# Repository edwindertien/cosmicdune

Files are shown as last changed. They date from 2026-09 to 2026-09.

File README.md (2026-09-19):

# cosmic dune -- sensor pod (manual)

One of 6 wearable pods for the *cosmic dune* project: an artistic laser
distress signal sent into the sky, triggered by 6 musicians' biosignals
synchronizing. Each pod reads one musician's heart rate (ear-clip pulse
sensor) and skin conductance (GSR), renders that live on a 250-LED strip
worn on the body and on an on-pod OLED display, and reports telemetry
over WiFi (OSC) to a central hub. The hub (gathering all 6 pods and
driving the Laserworld CUBE 3) is a separate, not-yet-built piece -- see
`context.md` for where that stands.

## Wiring

| Signal | Pico W pin  |
|---|---|
| Grove ear-clip signal | GP26 |
| Grove ear-clip VCC / GND | 3V3 / GND |
| GSR sensor signal | GP27 (ADC1) |
| GSR sensor VCC / GND | 3V3 / GND |
| LED strip data-in | GP17 |
| LED strip 5V / GND | **external 5V supply, NOT the Pico** -- common GND back to the Pico |
| OLED display (I2C0) SDA / SCL | GP8 / GP9 |
| M5Stack encoder (I2C1) SDA / SCL | GP6 / GP7 |

**Power, read this first:** 250x WS2812B at full white/full brightness is on
the order of 15A @ 5V -- far beyond USB or a small onboard regulator. Feed
the strip from its own adequately-rated 5V supply with a common ground back
to the Pico, and inject power at both ends of the 5m run if you see
dimming/colour-shift toward the far end. Normal operation (one travelling
comet, not the whole strip lit) draws much less than the full-white worst
case -- size the supply for the worst case anyway.

## Build

Requires [PlatformIO](https://platformio.org/) (VS Code extension or CLI).

```
pio run -t upload
pio device monitor
```

If the `pico_w` environment fails to resolve, check the note at the top of
`platformio.ini` -- the board id used by the `maxgerhardt` platform fork can
shift between versions. If a build fails on a missing header from a file
under `src/core/` or `src/net/`, double check that file actually exists at
that path locally -- these are newer folders in the project and it's easy
to end up with a file saved flat in `src/` instead of its subfolder.

## First bring-up (no sensors needed)

1. Flash and open the serial monitor (115200 baud).
2. `status` -- confirms the CLI is alive; should print `bpm=0 ... signal=no
   mode=ibi gsr=... net=off`.
3. `beat 72` -- injects one synthetic heartbeat. Confirms, with no sensors
   attached at all, that a white/blue comet travels the strip once, and
   the OLED's beat circle flashes with a pulse-waveform blip.
4. `beat 140 80` -- same, but with a synthetic 80% GSR level: the comet
   should read purple/red instead of white/blue (see `Config::gsrToColor`
   in `src/drivers/pulse_strip.cpp` to retune the gradient).
5. Clip on the ear-clip sensor, `stream on` -- watch live `bpm,ibiMs,signal`
   CSV lines. If `bpm` never moves off 0, or reads roughly double a manual
   pulse count, see the polarity note in `src/config.h` (`HW::PULSE_PIN`) --
   the sensor's beat edge may be RISING rather than the assumed FALLING on
   your specific module.
6. `gsr` -- watch the raw ADC count move as you rub your fingers together
   or relax. Set `gsr range <counts>` to whatever span actually takes you
   from white to red; `gsr invert on` if the colour runs backwards.
7. Turn the encoder knob -- press it to open the on-pod menu (see below).

## CLI reference

### Status / diagnostics
```
status                   bpm/IBI/signal + strip mode + GSR + net, one line
stream on|off             stream 't,bpm,ibiMs,signal' CSV lines (~10Hz)
beat [bpm] [gsrPct]       inject one synthetic heartbeat (default 72bpm,
                          live GSR reading) -- exercises the LED pulse with
                          no sensors attached; gsrPct (0-100) previews a
                          GSR level instead of using the live sensor
reboot
```

### LED strip
```
led brightness <0-255>   strip brightness (not persisted via CLI -- see
                          `save` below, or config.h HW::STRIP_DEFAULT_
                          BRIGHTNESS for the boot default)
mode fixed|ibi            fixed = constant traversal speed regardless of
                          BPM (fast heart rate -> multiple pulses in flight
                          at once); ibi = one traversal per heartbeat,
                          speed follows BPM (default)
mode speed <ms>            set the fixed-mode traversal time (default
                          config.h Config::FIXED_SPEED_TRAVERSAL_MS)
```

### GSR
```
gsr                       raw/baseline/range/inverted/normalized readout
gsr baseline [set|<raw>]  set = capture the current reading as the new
                          "calm" reference; <raw> sets it explicitly.
                          Auto-captured once at boot -- never persisted
                          (see context.md for why)
gsr range <counts>        raw ADC counts (12-bit) from baseline to "fully
                          sweaty" (default config.h Config::GSR_DEFAULT_RANGE)
                          -- widen if colour maxes to red too easily,
                          narrow if it barely leaves white
gsr invert on|off         flip if sweat reads as ADC counts DOWN on your
                          wiring instead of up
```

### WiFi / OSC telemetry
```
net                        WiFi/OSC config + live connection status
                          (password never echoed, only whether one is set)
net ssid <name>            set the WiFi SSID (may contain spaces)
net pass <pass>            set the WPA password (may contain spaces)
net pod <1-6>              this pod's id -- becomes the OSC address prefix
                          /pod/<id>/...  Set a DIFFERENT id on each of the
                          6 physical pods before saving, or they'll collide.
net hub <ip> <port>        hub's IP (dotted quad, not a hostname) + UDP port
net rate <1-60>            telemetry rate in Hz (default 15)
net enable|disable         turn WiFi/OSC telemetry on or off
net save                   persist current net settings to /netconfig.json
```
OSC messages sent per pod (see `src/net/osc_link.cpp`):
```
/pod/<id>/bpm      int    0 if no pulse signal
/pod/<id>/ibi      int    milliseconds
/pod/<id>/signal   int    0 or 1
/pod/<id>/gsrRaw   int    smoothed 12-bit ADC counts
/pod/<id>/gsr      float  0.0-1.0 normalized
```

### Persistence
```
save                       persist current GSR range/invert + strip
                          mode/speed to /podconfig.json
```
Two separate config files, two separate save commands -- `net save` for
WiFi (`/netconfig.json`), bare `save` for GSR/strip settings
(`/podconfig.json`). GSR **baseline** is never persisted by either.

## On-pod display and menu

An SH1107 OLED (M5Stack "Unit OLED", 128x64, I2C0) shows a live monitor
view when the menu isn't open:

- A beat indicator circle (top-left) -- hollow with no signal, flashes
  filled on each detected heartbeat.
- A "faux" heartbeat trace next to it, with the current BPM as a number.
  There's no raw analog waveform available from this sensor (it's a
  digital comparator, not analog PPG) -- this is a small stylized blip
  injected at the right edge and scrolled left once per *real* detected
  beat, similar in spirit to a bedside monitor's sweep display. The
  timing is genuine; the shape is synthetic.
- A GSR trend graph below that, with the current raw ADC count as a
  number next to it -- sampled roughly once a second (GSR moves on a
  timescale of seconds, so this gives close to a minute of visible trend).
- WiFi status/IP at the bottom.

An M5Stack Unit Encoder (I2C1, addr 0x40) drives an on-pod settings menu
over this same screen: rotate to navigate/adjust, short-press to
select/confirm, long-press to exit to the monitor view from anywhere.
Covers GSR range/invert/baseline-reset, strip mode/speed, brightness,
WiFi status (SSID shown, password only as set/not-set) and hub IP/port
(individually adjustable, since those are numeric), net enable, and
saving either settings group (`Save Pod` / `Save WiFi`). Entering an SSID
or password itself stays CLI-only -- typing free text with a rotary knob
isn't good UX no matter how it's built.

The menu is 17 items long, navigated as one flat scrolling list (not
grouped into submenus). Worth watching in practice: if that's tedious to
scroll through for routine adjustments, grouping related items behind a
submenu (e.g. one "WiFi" entry that opens its own short list) would be
the natural next step -- not built yet since it's unclear if the flat
list is actually a problem until it's used hands-on.

## Testing the OSC link without the real hub

`tools/` has two standalone Python scripts (`pip install -r
tools/requirements.txt`):

- **`osc_test_hub.py monitor`** -- terminal dashboard: listens for real (or
  simulated) pods and prints a live-refreshing table, including this
  machine's IP and the exact `net hub` command to point a pod at it.
- **`osc_test_hub.py simulate --pods 6`** -- sends fake telemetry for N
  synthetic pods, so anything downstream (the dashboard, eventually the
  real hub) can be developed and tested with zero physical hardware.
- **`osc_web_dashboard.py`** -- a graphical alternative to `monitor`: a
  Flask web page with live BPM (fixed 30-180 scale) and GSR (fixed 0-1
  scale) graphs per pod, plus the same status table (including each pod's
  source IP). Works with `osc_test_hub.py simulate` unchanged as a test
  data source -- both just listen on the same UDP port. Runs fine on a
  Raspberry Pi as well as a laptop.

## Known unverified assumptions

- **`board = rpipicow`** in `platformio.ini` -- see the note there.
- **Grove ear-clip edge polarity** (FALLING) -- flip to RISING in
  `src/drivers/pulse_sensor.cpp` if beats don't register or double-count.
- **GSR polarity and default range** -- both need calibrating per physical
  sensor/wearer; see the bring-up steps above.
- **Encoder rotation direction** -- `M5Encoder::readSteps()` returns
  positive for clockwise, ported from a previous project's assumption but
  not independently reconfirmed on this exact unit. If menu navigation
  feels backwards, flip the sign where it's consumed in `src/io/menu.cpp`.
- **`lib_ldf_mode = chain`** in `platformio.ini`, with
  `lib_ignore = lwIP_ESPHost` alongside it to exclude one irrelevant WiFi
  backend file that doesn't apply to this board (see `platformio.ini`'s
  comment, and the confirmed upstream issue it links, for why).

**Resolved, not concerns (kept here briefly since both looked like real
problems at first):** FastLED's `"Forcing software SPI"` build message is
about a code path (clocked SPI chipsets) we never use -- WS2812B goes
through FastLED's separate clockless controller, and RP2040 is confirmed
(FastLED's own docs) to re-enable interrupts between pixels rather than
holding them off for the whole frame. And the SH1107's `(64, 128)`
constructor argument order plus `setRotation(1)` in `display.cpp`'s
`begin()` are a real, confirmed-working pair for this exact 128x64
panel, not a mismatched typo -- see `context.md` for the full story on both.

## Deliberately deferred (not in this iteration)

- **USB MIDI** -- removed while debugging an unrelated CLI issue (see
  `context.md`); not yet reinstated.
- **Wired telemetry path** -- discussed (a WIZnet W5500 Ethernet module
  running the same OSC/UDP code, just swapping `WiFiUDP` for
  `EthernetUDP`) but not implemented. The CLI's `stream on` over USB is
  the current zero-extra-hardware fallback for bench use.
- **The hub itself** -- OSC-receiving + DMX/ILDA laser control for the
  Laserworld CUBE 3 is a separate, not-yet-started piece.
- **Per-pod physical labeling/workflow** for assigning and tracking which
  of the 6 physical pods has which `net pod <id>` -- currently manual and
  easy to get wrong across 6 units.
- **Menu grouping/submenus** -- see "On-pod display and menu" above.

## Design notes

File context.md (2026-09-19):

# cosmic dune -- sensor pod: design history & handover

This is the "why", not the "how" -- `README.md` covers wiring/build/CLI.
Written for whoever (including future Edwin) needs to pick this back up
without re-deriving every decision from scratch.

## The project, one level up

*cosmic dune*: an artistic project sending a laser distress signal into
the sky, requiring an ILT (Inspectie Leefomgeving en Transport) permit.
The signal is triggered by 6 musicians' biosignals synchronizing on stage.
Each musician wears a **pod** (this repo): a Raspberry Pi Pico W reading
their heart rate and skin conductance, driving a 250-LED strip and an
on-pod OLED display live, and reporting telemetry to a central **hub**
(not built yet) that watches all 6 pods for synchronization and drives
the actual Laserworld CUBE 3.

## Hardware decisions

- **Grove Ear-clip Heart Rate Sensor, not the analog PulseSensor-Amped
  module.** This one matters because it changes the whole sensing
  approach: it's a digital comparator output (idles HIGH, pulses LOW per
  beat), so beat detection is edge-timing + debounce on a plain GPIO, not
  ADC peak-detection. Confirmed against real hardware; the remaining
  unknown is which edge polarity this specific module uses (currently
  assumed FALLING, easy to flip if wrong -- see README).
- **GSR sensor on GP27/ADC1.**
- **250-LED WS2812B strip**, powered from its own 5V supply, not the
  Pico -- see README's power budget note (15A worst case at full
  white/full brightness).
- **SH1107 OLED (M5Stack "Unit OLED", 128x64) + M5Stack Unit Encoder**,
  added later as an on-pod display/menu alongside the CLI -- see below
  for the design decisions specific to these.

### Pin history

Pins moved more than once as the board's role grew:
- Heart rate: GP9 -> **GP26**, to free GP8/GP9 for the OLED's I2C0 bus.
- LED strip: GP6 -> GP10 (when GP6 became the encoder's I2C1 SDA) ->
  **GP17** on the actual physical build. `config.h` reflects the real
  wiring, not the intermediate guess.
- GSR stayed on GP27 throughout.

Current pinout is in README.md's wiring table; `config.h`'s `HW`
namespace is the single source of truth if the two ever disagree.

## Firmware architecture

- `src/drivers/` -- pulse_sensor (interrupt-driven beat detection),
  gsr_sensor (polled ADC + smoothing), pulse_strip (FastLED comet
  animation, two timing modes), display (SH1107 OLED), m5_encoder (raw
  I2C driver for the M5Stack Unit Encoder).
- `src/core/` -- net_config (WiFi/OSC settings) and pod_config (GSR/strip
  settings), each persisted to LittleFS as their own JSON file.
- `src/net/` -- osc_link (WiFi + OSC telemetry sender).
- `src/io/` -- cli (USB CDC serial) and menu (on-pod OLED+encoder settings UI).
- `src/main.cpp` -- wires it all together; boot order matters (see below).

## Decisions and why

### CLI + MIDI + WiFi combo, then MIDI came back out

The very first iteration ported a working TinyUSB CDC+MIDI composite
device pattern from an earlier Pico W project (the arm-controller repo),
on the theory that combining USB CDC (CLI) and USB MIDI would be useful
for a hub that (eventually) wants a literal MIDI "click" per heartbeat.
Once real hardware arrived, **the CLI produced no output or response at
all** -- not a logic bug, a boot hang. The suspects, in order: the
TinyUSB/MIDI mount-wait dance (copied from working code, so lower
suspicion), and FastLED's RP2040/PIO support (new to this project,
flagged unverified from the start).

Rather than keep guessing, the fix was to strip TinyUSB/MIDI out
entirely and go back to the arduino-pico core's plain, much better-tested
default USB CDC `Serial`. That fixed it. MIDI has not been reinstated --
it's not needed for the current OSC-based telemetry design (see below),
and reintroducing it means re-litigating the exact composite-device
ordering that was removed. If a literal MIDI output is wanted later
(e.g. for a DAW), treat it as a fresh, isolated addition, not a revert.

### FastLED's "Forcing software SPI" message -- resolved, was a false alarm

FastLED was chosen over Adafruit_NeoPixel specifically because it doesn't
disable interrupts for the whole frame on RP2040 -- important because
beat detection is interrupt-driven, and Adafruit_NeoPixel's RP2040 driver
is known to bit-bang with interrupts held off per frame. Build logs
repeatedly showed FastLED's `"Forcing software SPI - no hardware
accelerated SPI for you!"` pragma message, which looked like it might be
undermining that reasoning. It doesn't: that message is about FastLED's
*clocked SPI* output path (for chipsets like APA102/DotStar that need a
separate clock wire), which `fastspi.h` compiles unconditionally as part
of `FastLED.h` regardless of which chipset a sketch actually uses. WS2812B
(what we use) goes through FastLED's entirely separate *clockless*
controller instead -- the message is boilerplate about a code path we
never touch, not a statement about our actual LED output.

The real, relevant guarantee is FastLED's own documented per-platform
`FASTLED_ALLOW_INTERRUPTS` default: RP2040 is explicitly listed at the
"interrupts re-enabled between pixels" setting (unlike AVR/STM32, which
hold interrupts off for the entire frame). The pulse-sensor ISR just
timestamps an edge -- a handful of instructions, far under WS2812's
~30us-per-pixel budget -- so it's genuinely safe under this. FastLED was
the right call; this just needed sourcing properly instead of staying
flagged as an open question.

### Colour source moved from BPM to GSR

Originally the travelling pulse's colour was a function of heart rate
(white->blue->purple across a configurable BPM range). Once GSR was
added, colour was switched to depend on GSR instead (white->blue->
purple->red across GSR's already-normalized 0..1 range), with heart rate
now driving only motion/tempo. This is a deliberate separation of
concerns -- rhythm from the heart, colour from arousal.

### Two pulse timing modes

Added once it became clear that "one pulse takes one heartbeat's worth of
time to cross the strip" (`IBI_SYNCED`) doesn't handle a fast heart rate
gracefully with a single-comet design. `FIXED_SPEED` mode lets multiple
comets travel simultaneously at a constant, configurable speed --
switchable and tunable at runtime (`mode fixed|ibi`, `mode speed <ms>`,
or the on-pod menu), default stays `IBI_SYNCED`. `MAX_PULSES` was bumped
from 4 to 8 to give `FIXED_SPEED` mode headroom for a fast heart rate
against a slow configured traversal.

### Networking: OSC over WiFi, not Art-Net or BLE MIDI

Evaluated three options for pod -> hub telemetry:

| | OSC/UDP | Art-Net/WiFi | BLE MIDI |
|---|---|---|---|
| Library on Pico W | mature | mature (confirmed via `ArtnetWifi`, tested on Pico W) | none -- hand-rolled GATT service |
| Fits this data | natural (typed, addressable) | awkward (8-bit DMX channels, no native float) | ok for beat+CC, awkward for GSR |
| 6 senders -> 1 hub | trivial (stateless UDP listener) | workable but built for 1-controller->many-fixtures | 6 simultaneous BLE connections to one central -- unverified on this stack |
| Wired fallback, same code | yes (`WiFiUDP` -> `EthernetUDP`) | yes | no |

OSC won mainly because the data (BPM, IBI in ms, a 12-bit GSR reading)
doesn't shoehorn into 8-bit lighting channels without an unnecessary
encode/decode step, and because a UDP listener handles N independent
senders with no per-connection state, unlike BLE's central/peripheral
model. The wired alternative (WIZnet W5500 Ethernet module, same OSC
message code over `EthernetUDP`) was discussed but not built. The CLI's
`stream on` over USB is the current zero-hardware fallback for bench use.

### `OscLink` reads `netConfig` live, not a cached copy

First version of `OscLink::begin()` took a copy of `NetConfig` at boot.
Caught before shipping: since the CLI edits the global `netConfig`
directly (`net enable`, `net ssid`, ...), a cached copy would silently
stop reflecting those changes until reboot. Fixed by having `OscLink`
read the global directly. This exact class of bug -- a second copy of
config drifting from the live source of truth -- came up again with GSR/
mode persistence, and was avoided there from the start because of this.

### `PodConfigStore` reads/writes live sensor objects, not a mirrored struct

When GSR range/invert and strip mode/speed needed persisting, the
straightforward approach would have been a `PodConfig` struct mirroring
`NetConfig`'s shape. Deliberately not done that way: `PodConfigStore::
save()`/`load()` call `gsrSensor`'s and `pulseStrip`'s own getters/
setters directly. There is only ever one place these settings live,
avoiding a repeat of the `OscLink` staleness bug above.

**GSR baseline is deliberately never persisted**, in either the CLI or
the config file, or the on-pod menu -- `gsr_sensor.h`'s own comments
explain why: baseline is expected to need recalibrating most sessions,
sometimes even the same person on a different day, so saving a stale one
would actively work against the auto-calibration-at-boot design.
`gsrRange` and `gsrInverted` *are* persisted -- those describe the
sensor/wiring, not the wearer, and don't drift session to session.

### On-pod display + menu: sourced from a previous project, not built from scratch

Once the SH1107 OLED and M5Stack Unit Encoder were added, a previous Pico
project (`picoST3215DXL`, a servo controller using the exact same two
units, on different pins and sharing one I2C bus rather than two
separate ones) turned out to already have proven, working code for both
-- reviewing it resolved several things that would otherwise have stayed
guesses:

- **SH1107 orientation.** The constructor takes `(64, 128)` for this
  128x64 panel -- height first, confirmed against Adafruit's own official
  example -- but that alone leaves the coordinate system in the
  controller's native 64-wide "portrait" addressing. `picoST3215DXL`
  pairs this with `setRotation(1)`, which is what actually presents it as
  128x64 landscape to Adafruit_GFX. Passing `(64, 128)` without the
  matching `setRotation(1)` (an earlier version of this code did exactly
  that) produces a wrapped/corrupted image -- the two go together, not
  either alone.
- **M5Stack Unit Encoder register map.** Rather than depend on the
  official `m5stack/M5Unit-Encoder` Arduino library (whose exact
  `begin()` overload for a non-default I2C bus wasn't fully confirmed),
  `drivers/m5_encoder.cpp` talks to the device over raw I2C directly,
  using the register map `picoST3215DXL` already had working: `0x00`
  MODE, `0x10` ENCODER (2 bytes, little-endian, 2 counts per detent),
  `0x20` BUTTON (**active-low** -- that project's own code comment says
  plainly "Your module uses inverted logic", i.e. verified against real
  hardware), `0x30` RGB LED. This also dropped an entire external
  dependency (the official library) in favour of ~100 lines of
  already-proven code.
- **I2C bus recovery.** `picoST3215DXL` clocks SCL 9 times plus a manual
  STOP condition before `Wire.begin()`, to free a slave device left
  holding SDA low from a previous abrupt reset -- without this,
  `Wire.begin()` on RP2040 can hang indefinitely. Ported into both
  `display.cpp` and `m5_encoder.cpp`'s `begin()`, since each is its own
  physically separate I2C bus that can independently end up wedged.

One thing carried over as an assumption rather than independently
reconfirmed: `M5Encoder::readSteps()` returning positive for clockwise.

### On-pod menu: what's covered there vs. CLI-only

The menu grew in two passes. First pass covered GSR range/invert/
baseline-reset, strip mode/speed, brightness, and saving -- deliberately
excluding WiFi entirely, on the reasoning that entering an SSID/password
by turning a knob is bad UX regardless of implementation. Second pass
added WiFi *status* (SSID shown, password only as set/not-set -- same
convention as the CLI's `net`) and hub IP/port editing, once it was
clear those are different asks: numeric IP octets and a port number are
genuinely knob-friendly (handled via `IPAddress`'s own `operator[]`, not
hand-rolled string parsing), and viewing what's already configured isn't
the same as typing new text. Free-text SSID/password entry is still
excluded and still CLI-only.

This grew the menu to 17 flat (non-nested) items. Not yet clear whether
that's actually a UX problem in practice -- see README's note on
possible future submenu grouping.

### The graph redesign: BPM trend line -> "faux" pulse waveform

The OLED's first graph originally plotted a BPM value history (a normal
line chart, min/max scale, one point per beat). Replaced with a
scrolling waveform instead: a small stylized blip
(`{0, 1, -2, 8, -6, 2, -1, 0}`) gets injected at the right edge and
scrolled left, restarted from the beginning on every real detected beat.
The *timing* is genuine (driven by actual heartbeats); the *shape* is
synthetic, since the ear-clip sensor is a digital comparator with no raw
analog waveform to display -- hence "faux". Sweep speed is fixed (one
column per screen redraw, ~8.4s to cross the full width), independent of
actual heart rate, matching how a real bedside monitor's sweep works
(fixed paper/sweep speed, rate shown as a separate number). The BPM
number readout next to it is unchanged. `Screen::GRAPH_BPM_MIN/MAX` and
the old `_bpmHistory` ring buffer were removed as dead code, not left
around unused.

The GSR graph is a normal value-history trend line (unlike BPM's
waveform) since GSR doesn't have discrete "events" to trigger off --
sampled on its own ~1s timer, independent of the display's own ~100ms
redraw rate, since GSR moves far slower than either.

### Two repeats of the same C++ mistake, both real build breaks

Twice, a `namespace X` in `config.h` collided with a `class X` of the
same name elsewhere (`Display`/`Display`, then `Menu`/`Menu`) -- C++
doesn't allow a namespace and a class to share one name. Both were fixed
by renaming the *namespace* (to `Screen`, then `MenuCfg`), keeping the
class name intact since that's the more prominently-referenced identifier
everywhere else. Worth deliberately checking for this pattern before
introducing a new config namespace alongside a same-named class, since it
happened twice despite the first occurrence.

### `lib_ldf_mode`: deep+ -> chain+ -> off -> chain (+ lib_ignore)

Four rounds of build-tooling trouble, four different actual causes:
1. **deep+** (from the arm-controller project) got slow once FastLED was
   added -- it ships dozens of per-platform variant headers that `deep+`
   parses regardless of which one is actually used.
2. **chain+** was faster but slow again once WiFi + ArduinoJson + the
   CNMAT OSC library were added -- the OSC library, fetched raw from
   GitHub, has no PlatformIO registry manifest, which triggers `chain+`'s
   expensive fallback scanning for libraries with unclear metadata.
3. **off** (every used library explicit in `lib_deps`, no automatic
   discovery) seemed to fix it -- until it broke `Wire.h`/`LittleFS.h`
   resolution outright once the SH1107/encoder libraries reshuffled the
   dependency graph. Turns out `off` also blocks discovery of
   framework-*bundled* headers, not just third-party ones; it had only
   appeared to work due to leftover build cache from before `off` was set.
4. **chain** (current): real dependency discovery restored, without
   `chain+`/`deep+`'s extra exhaustive-scan pass (the actual source of
   the earlier slowness, not discovery itself). This in turn exposed a
   separate, confirmed-upstream issue: arduino-pico bundles all its WiFi
   backends (CYW43, ESPHost, WINC1500) under one library folder, and
   `chain` compiles every file in a library it pulls in -- including
   `lwIP_ESPHost.cpp`, meant only for boards with an external ESP32
   co-processor, which hard-fails to compile for `rpipicow` (needs a pin
   macro that's never defined for this board). Fixed with
   `lib_ignore = lwIP_ESPHost` in `platformio.ini` -- confirmed as a real,
   currently-open, unresolved issue in `maxgerhardt/platform-raspberrypi`
   (#83), not something specific to this project.

### CLI bugs worth knowing about (already fixed, but instructive)

- **Leftover files still compiled after removal from `lib_deps`.**
  PlatformIO compiles every `.cpp` under `src/` as its own translation
  unit regardless of whether anything still includes it. Deleting
  `midi_engine.cpp`/`midi_bridge.cpp` from `lib_deps` didn't stop them
  compiling -- the files had to be deleted from disk.
- **Silent fallthrough on malformed subcommands.** `net hub`, `net pod`,
  and `net rate` originally matched via a combined `a == "x" && n >= N`
  condition -- so `net hub <ip>` with a missing port didn't print a
  hub-specific error, it fell through to the generic multi-command usage
  text and was easy to miss. This is exactly what caused a real
  debugging session: `net save` appeared to succeed, but `net hub` had
  silently never taken effect, so telemetry silently never sent. Fixed by
  checking the subcommand keyword first, independent of argument count.
- **python-osc wildcard matching uncertainty.** The Python test tools
  deliberately use one `set_default_handler` with manual
  `"/pod/<id>/<leaf>"` parsing rather than per-address wildcard mappings
  like `/pod/*/bpm` -- OSC wildcard semantics vary enough between
  implementations that this felt safer to verify than trust, and was
  confirmed end-to-end with a live send/receive test rather than just
  read from docs.

## Current state (as of this writing)

Confirmed working on real hardware: pulse sensing, GSR sensing + colour
mapping, both pulse timing modes, WiFi connect + OSC telemetry to a real
hub-side listener, LittleFS persistence for both config files, the
SH1107 display (monitor view + menu), the M5Stack encoder (navigation,
short/long press), the full build (all libraries resolving, `chain` +
`lib_ignore` combination). `osc_test_hub.py` (terminal monitor +
simulate) and `osc_web_dashboard.py` (Flask graphical dashboard) both
verified end-to-end against real pod traffic.

Not yet built: the actual hub (OSC-receiving + DMX/ILDA control of the
Laserworld CUBE 3), USB MIDI reinstatement, the wired Ethernet fallback,
any workflow for keeping 6 physical pods' `net pod` ids straight, menu
submenu grouping (if the current flat 17-item list turns out to need it).

## Open questions for next time

- Default `PulseMode` for actual performance use -- `ibi` (current
  default) or `fixed`? Needs eyes-on with real musicians, not a desk
  decision.
- Encoder rotation direction (`readSteps()` positive = clockwise) --
  carried over as an assumption from the reference project, not
  independently reconfirmed on this exact unit.
- Whether the 17-item flat menu needs grouping into submenus once used
  hands-on for real adjustments, or whether that's over-engineering a
  problem that doesn't actually bite in practice.
- Laser control path: DMX (preset patterns, coarse) vs ILDA (via an
  external DAC, full custom vector control) for the CUBE 3 -- see the
  laser-control discussion for where this landed.

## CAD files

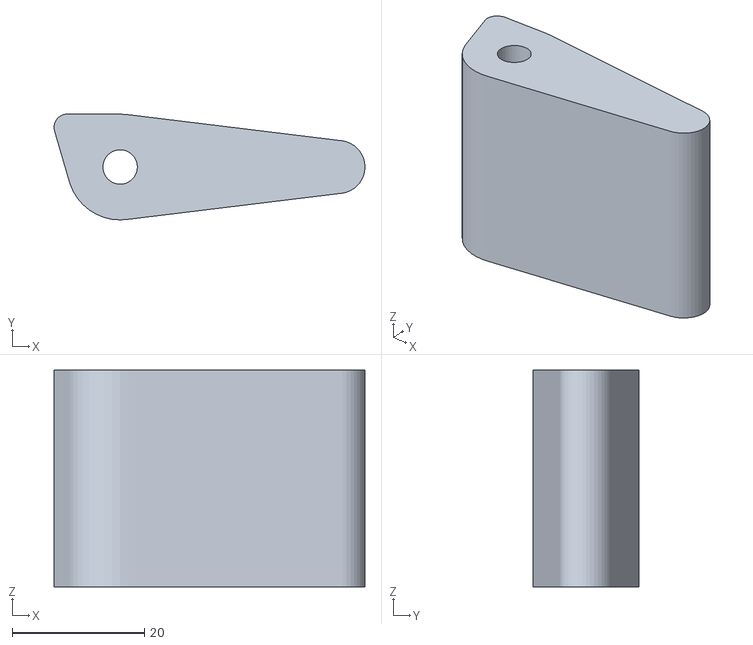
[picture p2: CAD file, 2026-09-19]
design/pi-case/leg.stl
47.0 x 16.0 x 32.8

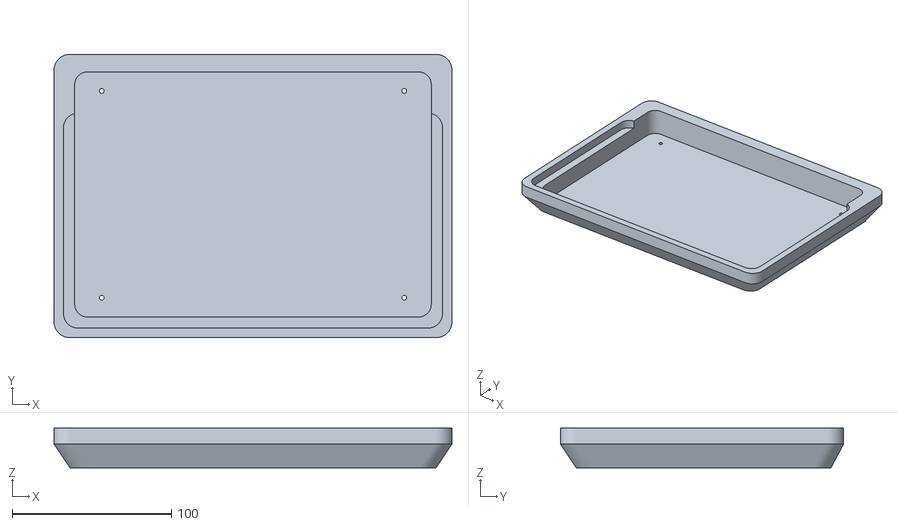
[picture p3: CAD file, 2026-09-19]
design/pi-case/casebottom.stl
250.0 x 178.0 x 25.0

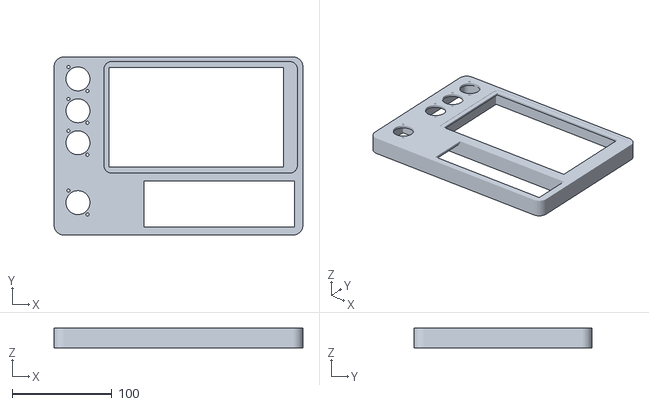
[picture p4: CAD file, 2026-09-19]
design/pi-case/casetop.stl
249.5 x 178.5 x 20.0

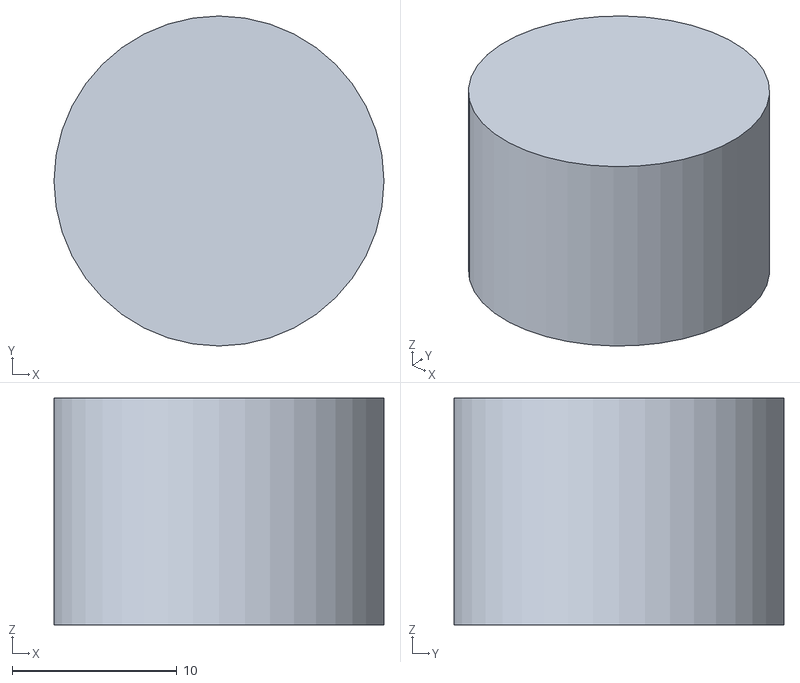
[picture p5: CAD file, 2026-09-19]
design/pi-case/cylinder.stl
20.0 x 20.0 x 13.8

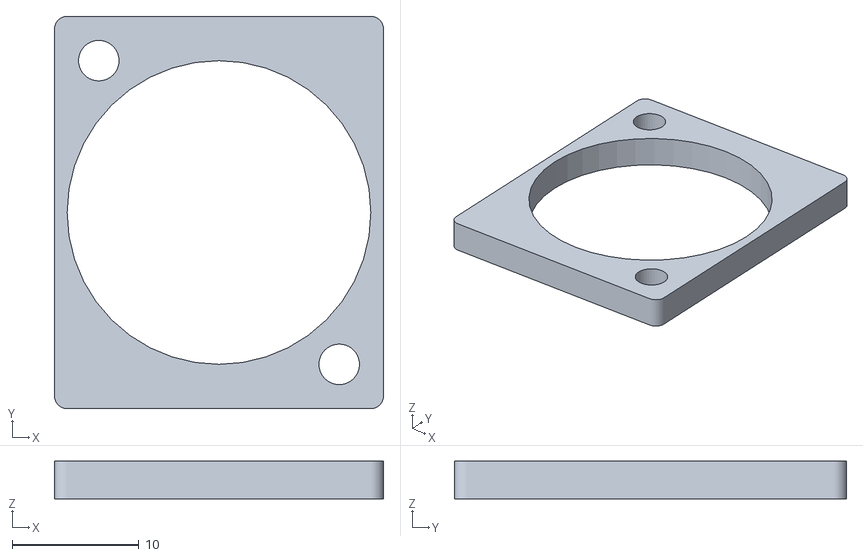
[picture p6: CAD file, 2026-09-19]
design/pi-case/neutrikadapter.stl
26.0 x 31.0 x 3.00

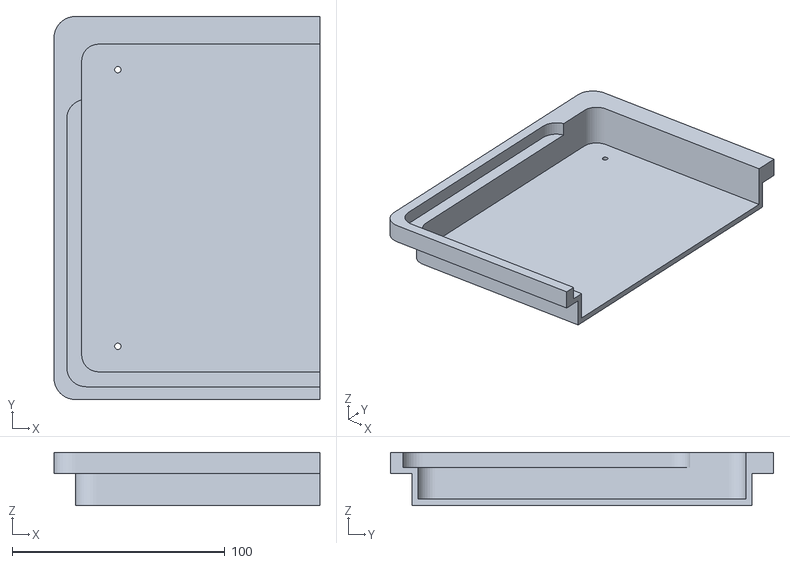
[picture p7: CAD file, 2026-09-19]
design/pi-case/casebottomhalf.stl
125.0 x 180.0 x 25.0

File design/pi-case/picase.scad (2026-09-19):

$fn = 40;
bottom();
module top(){
difference(){
translate([0,0,-20])plate(249.5,178.5,10,20);
translate([5,5,-23])plate(240,168.5,5,20);
    
    translate([90,8,-10])cube([151,46,40]);
    translate([55,68,-10])cube([175,100,30]);
    
    translate([50,62,-0.5])plate(194,112,8,4);
    translate([12,142,-5])neutrik();
    translate([12,110,-5])neutrik();
    translate([12,78,-5])neutrik();

    translate([12,18,-5])neutrik();
}

translate([0,56,-20])cube([249.5,5,19]);
translate([44,0,-20])cube([5,178,19]);
}
module neutrik(){
    hull(){
        translate([0,0,0])cylinder(d=2,h=2);
        translate([24,29,0])cylinder(d=2,h=2);
        translate([24,0,0])cylinder(d=2,h=2);
        translate([0,29,0])cylinder(d=2,h=2);
    }
    translate([12,14.5,2])cylinder(d=24,h=5);
    translate([2.5,26.5,2])cylinder(d=3.2,h=5);
    translate([2.5+19,26.5-24,2])cylinder(d=3.2,h=5);
}

//difference(){
//    bottom();
//    translate([125,-10,-10])cube([300,300,300]);
//}

module bottom(){
difference(){
hull(){
translate([0,0,15])plate(250,178,10,10);
translate([10,10,0])plate(230,160,10,15);
    
}
translate([30,25,-0.01])cylinder(d=6.5,h=1);
translate([30+190,25,-0.01])cylinder(d=6.5,h=1);
translate([30+190,130+25,-0.01])cylinder(d=6.5,h=1);
translate([30,130+25,-0.01])cylinder(d=6.5,h=1);

translate([13,13,3])plate(224,154,8,30);

translate([6,6,18])plate(238,135,9,10);

translate([30,25,-0.01])cylinder(d=3,h=10);
translate([30+190,25,-0.01])cylinder(d=3,h=10);
translate([30+190,130+25,-0.01])cylinder(d=3,h=10);
translate([30,130+25,-0.01])cylinder(d=3,h=10);
}

}

module plate(width,depth,corner,height){hull(){
    translate([corner, corner, 0])cylinder(r=corner,h=height);
    translate([width-corner, corner, 0])cylinder(r=corner,h=height);
    translate([width-corner, depth-corner, 0])cylinder(r=corner,h=height);
    translate([corner, depth-corner, 0])cylinder(r=corner,h=height);
}}

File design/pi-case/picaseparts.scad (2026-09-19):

$fn = 40;

module leg(){
difference(){

hull(){
    cylinder(d=16,h=32.75);
    translate([33,0,0])cylinder(d=8,h=32.75);
    translate([-8,0,0])cube([8,8,32.75]);
    translate([-8,6,0])cylinder(d=4,h=32.75);
    
}
cylinder(d=5.2,h=35);
}
}

cylinder(d=20,h=13.75);

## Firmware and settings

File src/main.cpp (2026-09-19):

#include <Arduino.h>
#include "config.h"
#include "drivers/pulse_sensor.h"
#include "drivers/gsr_sensor.h"
#include "drivers/pulse_strip.h"
#include "drivers/display.h"
#include "core/net_config.h"
#include "core/pod_config.h"
#include "net/osc_link.h"
#include "io/cli.h"
#include "io/menu.h"

// ---------------------------------------------------------------------------
// cosmic dune -- sensor pod firmware, iteration 1e:
//   Grove ear-clip pulse (GP26) sets the travelling pulse's speed/tempo;
//   GSR (GP27) sets its colour (white -> blue -> purple -> red). Both
//   render on the 250-LED strip (GP17). Telemetry (bpm/ibi/signal/gsr)
//   goes out over WiFi as OSC to a hub, once configured via the CLI's
//   `net` commands. An SH1107 OLED (I2C0, GP8/GP9) shows a live
//   beat-flash + BPM graph + WiFi status, and an M5Stack encoder (I2C1,
//   GP6/GP7) drives an on-pod settings menu for GSR/strip settings --
//   see io/menu.h for exactly what's covered there vs. CLI-only. The USB
//   CLI keeps working unmodified alongside all of this.
// ---------------------------------------------------------------------------

static void onBeat(uint16_t bpm, uint32_t ibiMs) {
  (void)ibiMs;
  pulseStrip.trigger(bpm, gsrSensor.normalized());
  display.notifyBeat();
}

void setup() {
  Serial.begin(115200);
  delay(50);
  Serial.println(F("=== cosmic dune sensor pod booting ==="));

  cli.begin();

  Serial.println(F("[BOOT] arming pulse sensor on GP26..."));
  pulseSensor.begin(HW::PULSE_PIN);
  pulseSensor.setOnBeat(onBeat);
  Serial.println(F("[BOOT] pulse sensor armed"));

  Serial.println(F("[BOOT] calibrating GSR baseline on GP27 (~0.5s, hold still)..."));
  gsrSensor.begin(HW::GSR_PIN);
  Serial.print(F("[BOOT] GSR baseline=")); Serial.println(gsrSensor.baseline());

  Serial.println(F("[BOOT] starting LED strip (FastLED, GP17, 250 LEDs)..."));
  pulseStrip.begin();
  Serial.println(F("[BOOT] LED strip ready"));
  // If "[BOOT] LED strip ready" never appears, FastLED.addLeds() (in
  // pulse_strip.cpp) is hanging/panicking -- comment out the
  // pulseStrip.begin() line above and reflash to confirm.

  Serial.println(F("[BOOT] starting OLED display (I2C0, GP8/GP9)..."));
  display.begin();
  Serial.println(F("[BOOT] display ready"));

  Serial.println(F("[BOOT] starting menu + encoder (I2C1, GP6/GP7)..."));
  menu.begin();
  Serial.println(F("[BOOT] encoder armed -- press it to open the on-pod menu"));
  // If either of the two lines above never completes, the encoder
  // library's begin() overload is the prime suspect -- see
  // drivers/m5_encoder.h's header comment for exactly what's unverified there.

  // PodConfigStore::load() runs AFTER the sensor/strip begin() calls
  // above so it overrides their compiled-in defaults, not the other way
  // around -- GSR baseline itself is untouched either way (see
  // pod_config.h for why it's not persisted).
  PodConfigStore::begin();
  if (PodConfigStore::load()) {
    Serial.println(F("[BOOT] loaded /podconfig.json (GSR range/invert, strip mode/speed)"));
  } else {
    Serial.println(F("[BOOT] no /podconfig.json yet -- using config.h defaults "
                      "(see CLI/menu 'save' to persist current gsr/mode settings)"));
  }

  Serial.println(F("[BOOT] mounting LittleFS for network config..."));
  NetConfigStore::begin();
  if (NetConfigStore::load(netConfig)) {
    Serial.println(F("[BOOT] loaded /netconfig.json"));
  } else {
    Serial.println(F("[BOOT] no /netconfig.json yet -- WiFi stays off until "
                      "configured (see CLI 'net') and saved ('net save')"));
  }
  oscLink.begin();

  Serial.println(F("=== pod ready -- type 'help', or press the encoder for the menu ==="));
}

void loop() {
  gsrSensor.tick();   // samples + smooths on its own timer (no-op most
                        // loop() iterations -- see Timing::GSR_SAMPLE_MS)
  pulseSensor.tick(); // drains the beat ISR flag; fires onBeat() when a
                        // new beat has been confirmed
  if (pulseSensor.hasSignal()) {
    pulseStrip.tick();
  } else {
    pulseStrip.idle();
  }
  oscLink.tick(); // (re)connects WiFi on its own timer; a cheap no-op
                   // once connected, or always if `net` is unconfigured
  oscLink.sendTelemetry(pulseSensor.bpm(), pulseSensor.lastIbiMs(),
                         pulseSensor.hasSignal(), gsrSensor.raw(),
                         gsrSensor.normalized()); // rate-limited internally;
                                                    // a no-op if not connected

  menu.tick(); // always -- polls the encoder (incl. detecting the button
                // press that opens the menu) and, once open, handles its
                // own input + drawing every call
  if (!menu.isOpen()) {
    // The menu owns the screen while open; this is the normal view the
    // rest of the time. Only ever shows the pod's OWN IP (from WiFi.
    // localIP() via oscLink), not the hub's -- there's no reason for a
    // pod to know the hub's address, only the other way around.
    String ipText = oscLink.connected() ? oscLink.localIp().toString() : String();
    display.renderMonitor(ipText, oscLink.connected(), pulseSensor.hasSignal(),
                           pulseSensor.bpm(), gsrSensor.raw(), gsrSensor.normalized());
  }

  cli.tick();
}

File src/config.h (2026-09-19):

#pragma once
#include <Arduino.h>

// =============================================================================
// HARDWARE CONFIGURATION -- cosmic dune sensor pod, Raspberry Pi Pico W
//
// Interaction is now both CLI (USB CDC) and an on-pod SH1107 OLED + M5Stack
// encoder -- see io/menu.h for the split of what's adjustable where.
// =============================================================================
namespace HW {
  // Grove Ear-clip Heart Rate Sensor: onboard comparator, DIGITAL output
  // (idles HIGH, pulses LOW on each detected beat) -- this is NOT the
  // analog PulseSensor-Amped module, so there's no ADC/peak-detection here,
  // just edge timing. Moved from GP9 to GP26 to free GP8/GP9 for I2C0
  // (below) -- GP26 is ADC-capable but that's irrelevant here, it's just
  // used as a plain digital input.
  // NOTE (unverified against the physical module -- confirm with `beat`
  // vs. a live earclip and the `status` command): if beats never register,
  // or register at roughly double a manually-checked pulse, the edge
  // polarity in drivers/pulse_sensor.cpp (currently FALLING) is the first
  // thing to flip to RISING.
  static constexpr uint8_t PULSE_PIN = 26; // GP26

  // GSR (galvanic skin response) sensor -- analog, GP27/ADC1, unchanged by
  // this pinout revision. Sets the travelling pulse's colour (see
  // Config::gsrToColor's white->blue->purple->red gradient in
  // pulse_strip.cpp); heart rate (PULSE_PIN) still drives motion/tempo,
  // independently.
  static constexpr uint8_t GSR_PIN = 27; // GP27 / ADC1

  // WS2812B-style ("neopixel") strip, 5m @ 50 LED/m. Originally moved
  // from GP6 to GP10 when GP6 became I2C1 SDA, then wired to GP17 on the
  // physical build instead. FastLED's PIO-based driver isn't tied to
  // specific pins the way I2C/SPI hardware peripherals are, so this is
  // just a constant change, nothing structural.
  static constexpr uint8_t  STRIP_PIN                = 17;  // GP17
  static constexpr uint16_t STRIP_NUM_LEDS           = 250;
  static constexpr uint8_t  STRIP_DEFAULT_BRIGHTNESS = 120; // 0-255, FastLED global scale
  // POWER BUDGET, READ BEFORE FIRST POWER-ON: 250x WS2812B at full white,
  // full brightness draws on the order of 15A @ 5V -- nowhere near what a
  // Pico's USB/VBUS or a small 5V regulator can supply. This strip needs
  // its own adequately-rated 5V supply, fed into the strip directly (not
  // through the Pico), with a common GND back to the Pico, and injected at
  // both ends of a 5m run if you see colour-shift/dimming toward the far
  // end from voltage drop. STRIP_DEFAULT_BRIGHTNESS=120 and the fact that
  // only a travelling comet (not the whole strip) is ever lit keeps typical
  // draw far below the full-white worst case, but size the supply and wire
  // gauge for the worst case, not the typical one.

  // I2C0 -- SH1107 OLED (M5Stack "Unit OLED", 128x64, addr 0x3C). GP8/GP9
  // is a valid RP2040 I2C0 pin pair (GPIO%4==0 -> I2C0 SDA, %4==1 -> I2C0
  // SCL) -- confirmed against the RP2040 GPIO function table, not guessed.
  static constexpr uint8_t I2C0_SDA = 8; // GP8
  static constexpr uint8_t I2C0_SCL = 9; // GP9
  static constexpr uint8_t DISPLAY_I2C_ADDR = 0x3C;

  // I2C1 -- M5Stack Unit Encoder (addr 0x40). GP6/GP7 is a valid RP2040
  // I2C1 pin pair (GPIO%4==2 -> I2C1 SDA, %4==3 -> I2C1 SCL), same
  // confirmation basis as I2C0 above.
  static constexpr uint8_t I2C1_SDA = 6; // GP6
  static constexpr uint8_t I2C1_SCL = 7; // GP7
  static constexpr uint8_t ENCODER_I2C_ADDR = 0x40;

  // Confirmed working value from a previous project using the same OLED
  // and encoder units (picoST3215DXL) -- applied to both I2C buses.
  static constexpr uint32_t I2C_HZ = 400000UL;

  // Onboard status LED. On Pico W, LED_BUILTIN is routed through the CYW43
  // WiFi chip by the arduino-pico core (not a plain GPIO) -- digitalWrite()
  // on it still works, but confirm this on your specific core version.
  static constexpr int16_t LED_PIN = LED_BUILTIN;

  // Not used by this pinout revision, and not available even if you
  // wanted them: GP23/24/25/29 are wired internally to the Pico W's CYW43
  // WiFi chip, not exposed as general-purpose GPIO on this board.
}
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

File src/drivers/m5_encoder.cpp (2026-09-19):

#include "m5_encoder.h"

M5Encoder m5Encoder;

void M5Encoder::begin() {
  // I2C bus recovery -- see display.cpp's begin() for the full
  // explanation; same technique, applied here since I2C1 is a physically
  // separate bus that can just as easily be left wedged by an abrupt reset.
  pinMode(HW::I2C1_SDA, INPUT_PULLUP);
  pinMode(HW::I2C1_SCL, OUTPUT);
  for (int i = 0; i < 9; ++i) {
    digitalWrite(HW::I2C1_SCL, HIGH); delayMicroseconds(5);
    digitalWrite(HW::I2C1_SCL, LOW);  delayMicroseconds(5);
  }
  pinMode(HW::I2C1_SDA, OUTPUT);
  digitalWrite(HW::I2C1_SDA, LOW);
  digitalWrite(HW::I2C1_SCL, HIGH); delayMicroseconds(5);
  digitalWrite(HW::I2C1_SDA, HIGH); delayMicroseconds(5);

  Wire1.setSDA(HW::I2C1_SDA);
  Wire1.setSCL(HW::I2C1_SCL);
  Wire1.begin();
  Wire1.setClock(HW::I2C_HZ);

  uint8_t mode = 0;
  writeBytes(MODE_REG, &mode, 1);

  _lastRawCount   = readRawCount();
  _lastRawButton  = readButtonRaw();
  _stableButton   = _lastRawButton;
  _lastDebounceMs = millis();
}

bool M5Encoder::writeBytes(uint8_t reg, const uint8_t* buffer, uint8_t length) {
  Wire1.beginTransmission(HW::ENCODER_I2C_ADDR);
  Wire1.write(reg);
  for (uint8_t i = 0; i < length; ++i) Wire1.write(buffer[i]);
  return Wire1.endTransmission() == 0;
}

bool M5Encoder::readBytes(uint8_t reg, uint8_t* buffer, uint8_t length) {
  Wire1.beginTransmission(HW::ENCODER_I2C_ADDR);
  Wire1.write(reg);
  if (Wire1.endTransmission() != 0) return false;
  if (Wire1.requestFrom((int)HW::ENCODER_I2C_ADDR, (int)length) != length) return false;
  for (uint8_t i = 0; i < length; ++i) buffer[i] = Wire1.available() ? Wire1.read() : 0;
  return true;
}

int16_t M5Encoder::readRawCount() {
  uint8_t data[2] = {0, 0};
  if (!readBytes(ENCODER_REG, data, 2)) return _lastRawCount;
  return (int16_t)(data[0] | (data[1] << 8));
}

bool M5Encoder::readButtonRaw() {
  uint8_t data = 0;
  if (!readBytes(BUTTON_REG, &data, 1)) return _stableButton;
  return data == 0; // active-LOW -- confirmed against real hardware, see header
}

void M5Encoder::update() {
  _shortPressEvent = false;
  _longPressEvent  = false;

  int16_t raw = readRawCount();
  int16_t delta = (int16_t)(raw - _lastRawCount);
  _lastRawCount = raw;
  _stepAccumulator += delta;

  bool rawButton = readButtonRaw();
  if (rawButton != _lastRawButton) {
    _lastRawButton = rawButton;
    _lastDebounceMs = millis();
  }
  if ((millis() - _lastDebounceMs) < DEBOUNCE_MS) return;

  if (_stableButton != _lastRawButton) {
    _stableButton = _lastRawButton;
    if (_stableButton) {
      _pressStartMs = millis();
      _longPressFired = false;
    } else {
      if (_waitForReleaseAfterLong) {
        _waitForReleaseAfterLong = false;
      } else if (_pressStartMs != 0 && !_longPressFired &&
                 (millis() - _lastEventMs) > EVENT_GAP_MS) {
        _shortPressEvent = true;
        _lastEventMs = millis();
      }
      _pressStartMs = 0;
      _longPressFired = false;
    }
  }

  if (_stableButton && !_longPressFired && !_waitForReleaseAfterLong &&
      _pressStartMs != 0 && (millis() - _pressStartMs) >= LONGPRESS_MS &&
      (millis() - _lastEventMs) > EVENT_GAP_MS) {
    _longPressEvent = true;
    _longPressFired = true;
    _waitForReleaseAfterLong = true;
    _lastEventMs = millis();
  }
}

int M5Encoder::readSteps() {
  int steps = 0;
  while (_stepAccumulator >= COUNTS_PER_STEP) { _stepAccumulator -= COUNTS_PER_STEP; steps++; }
  while (_stepAccumulator <= -COUNTS_PER_STEP) { _stepAccumulator += COUNTS_PER_STEP; steps--; }
  return steps;
}

bool M5Encoder::wasShortPressed() {
  bool e = _shortPressEvent;
  _shortPressEvent = false;
  return e;
}

bool M5Encoder::wasLongPressed() {
  bool e = _longPressEvent;
  _longPressEvent = false;
  return e;
}

bool M5Encoder::isPressed() const { return _stableButton; }

void M5Encoder::clearEvents() {
  _shortPressEvent = false;
  _longPressEvent  = false;
  _stepAccumulator = 0;
  _pressStartMs = 0;
  _longPressFired = false;
  _lastDebounceMs = millis();
  if (!_stableButton) {
    _lastRawButton = false;
    _waitForReleaseAfterLong = false;
  } else {
    _waitForReleaseAfterLong = true; // still held after a long press -- swallow the upcoming release
  }
}

void M5Encoder::setLedColor(uint8_t index, uint32_t rgb24) {
  uint8_t data[4];
  data[0] = index;
  data[1] = (rgb24 >> 16) & 0xFF;
  data[2] = (rgb24 >> 8) & 0xFF;
  data[3] = rgb24 & 0xFF;
  writeBytes(RGB_LED_REG, data, 4);
}

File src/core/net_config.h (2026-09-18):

#pragma once
#include <Arduino.h>

// ---------------------------------------------------------------------------
// NetConfig -- this pod's WiFi + OSC-hub settings, set via the CLI's
// `net ...` commands and persisted to LittleFS (NetConfigStore below) so
// they survive reflashing/rebooting -- nothing here is compiled in.
//
// SSID/password buffers match the real 802.11/WPA2 maximums (32/63 chars),
// same reasoning as the arm-controller project's AP credential buffers.
// ---------------------------------------------------------------------------
struct NetConfig {
  uint8_t  podId = 1; // this pod's id, 1-6 -- becomes the OSC address
                       // prefix /pod/<id>/... that osc_link.cpp sends to
  char     ssid[33]     = "";
  char     password[64] = "";
  char     hubHost[40]  = ""; // hub's IP, e.g. "192.168.1.50" -- a dotted
                                // quad only, not resolved as a hostname
  uint16_t hubPort = 9000;
  uint8_t  sendHz  = 15; // telemetry rate per pod

  // Stays false until deliberately configured -- a pod with no SSID set
  // shouldn't spend every boot retrying a WiFi connect it can't complete.
  // See CLI `net enable` / `net disable`.
  bool enabled = false;
};

extern NetConfig netConfig;

namespace NetConfigStore {
  bool begin();               // mounts LittleFS -- formats on first-ever boot
  bool load(NetConfig& cfg);  // false if no file yet / parse failed --
                                // caller should keep the struct's defaults
  bool save(const NetConfig& cfg);
}

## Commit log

2026-09-19 added pi case files and updated doc
    [casebottom.stl, casebottomhalf.stl, casetop.stl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]
2026-10-20 laser test continues
